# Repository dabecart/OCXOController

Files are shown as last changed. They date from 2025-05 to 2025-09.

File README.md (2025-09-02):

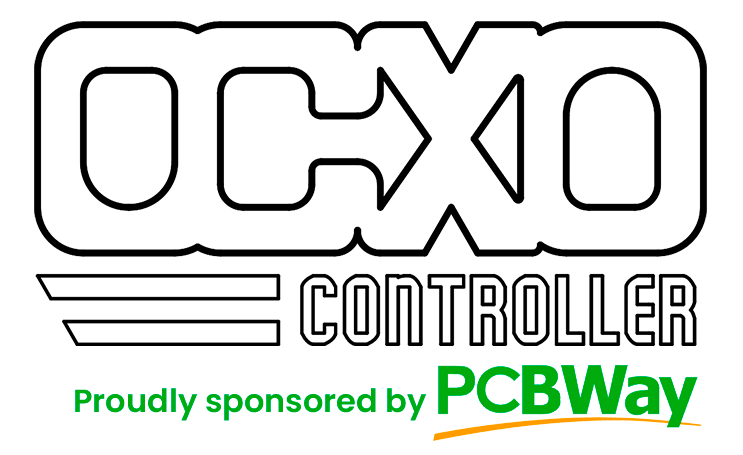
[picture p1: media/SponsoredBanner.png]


# OCXO Controller

By @dabecart, 2025.

✨ This project was sponsored by [**PCBWay**](#a-huge-thank-you-to-pcbway) ✨

Control the frequency of an OCXO (Oven Controlled Crystal Oscillator) to synchronize it with an external
signal of reference. Use it on a radio transmitter or for precision frequency measurement!

# Video

<a href="http://www.youtube.com/watch?feature=player_embedded&v=DMhajk4vEt8
" target="_blank">OCXOControllerVideo</a>

# Gallery

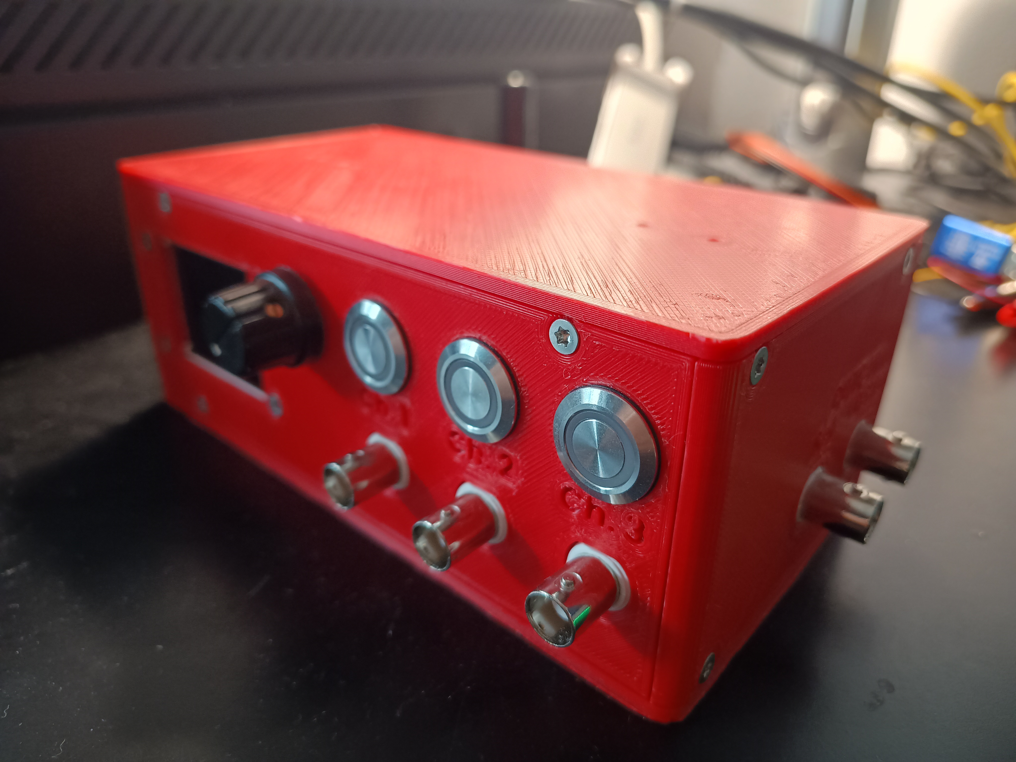
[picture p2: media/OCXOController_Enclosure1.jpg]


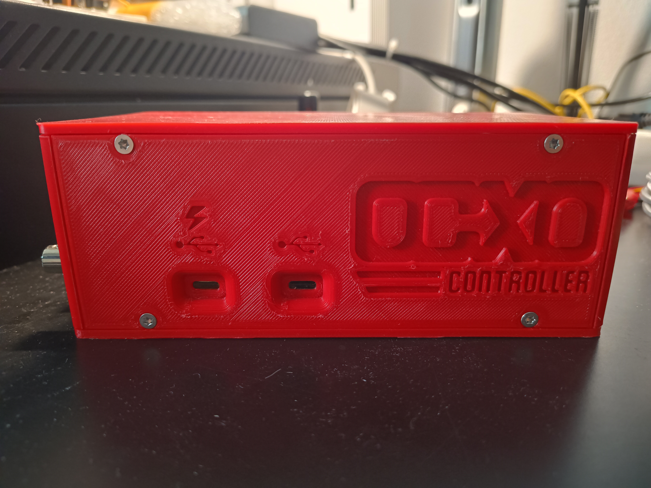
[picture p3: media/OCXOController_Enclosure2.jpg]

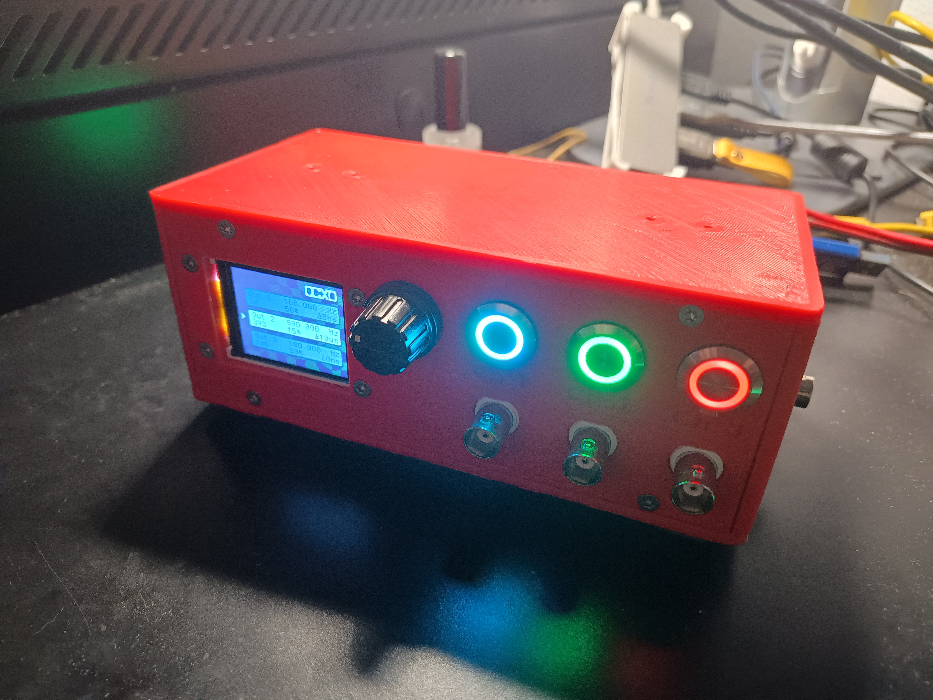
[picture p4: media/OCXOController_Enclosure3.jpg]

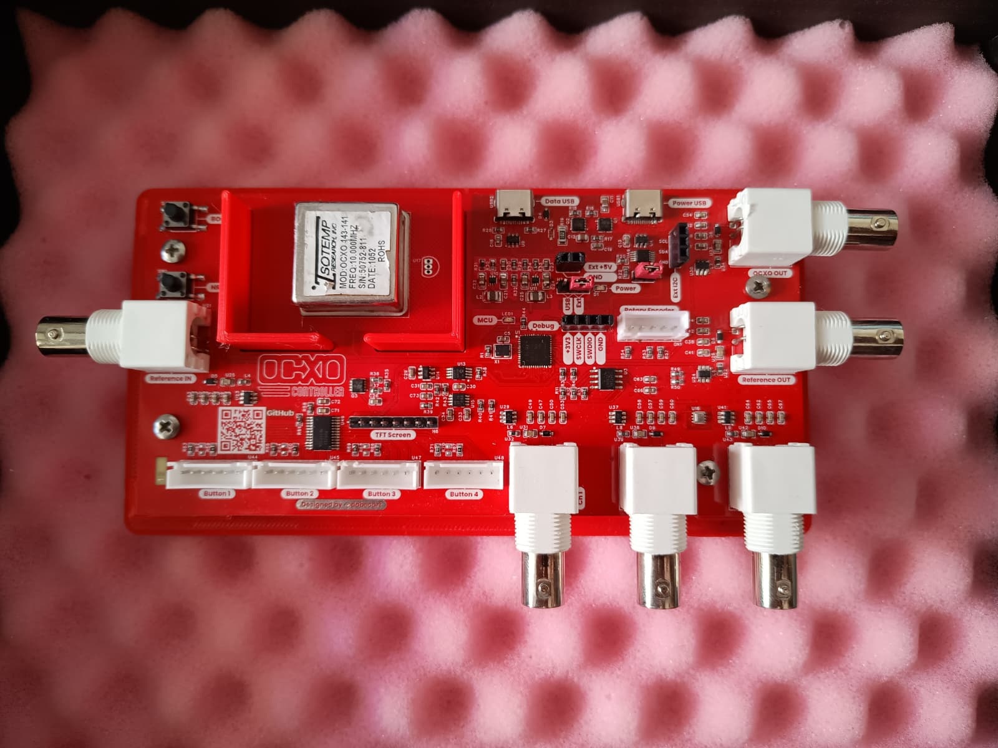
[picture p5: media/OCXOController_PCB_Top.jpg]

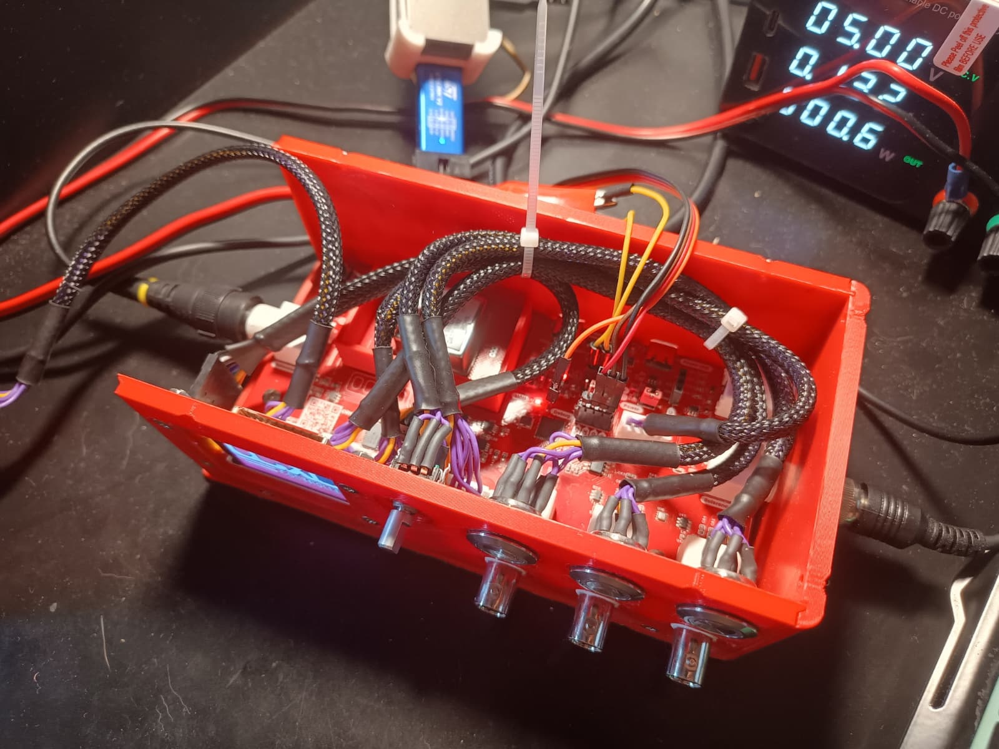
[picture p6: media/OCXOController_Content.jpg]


# A Huge Thank You to PCBWay! 

Whether you're a hobbyist, engineer, or student, I feel confident in saying that they're the go-to destination for high-quality PCB manufacturing and prototyping.

Here are just a few of the reasons why PCBWay stands out:

✅ Top-notch Quality: After thoroughly inspecting all of the PCBs of my project, I was content with the great precision the PCBs were made. I felt they are reliable and durable!

✅ Fast Turnaround: The whole ordering, manufacturing and shipping of the PCBs and the stencil to Spain took around a week and a half, which is most impressing! 

✅ Affordable Pricing: Their competitive rates make professional-grade PCBs accessible to everyone.

✅ Excellent Support: From order placement to final delivery, PCBWay’s team was always there to answer my questions and provide guidance.

Thanks to their expertise and dedication, I was able to turn my ideas for this project into reality without a hitch. If you’re working on your next PCB project, I can’t recommend PCBWay enough!

🎉 Visit [**PCBWay.com**](https://www.pcbway.com/) and experience their amazing service for yourself!

✨ And a final thanks to PCBWay for their patronage! ✨

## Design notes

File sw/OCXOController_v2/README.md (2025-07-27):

# OCXO Controller 

*Created by @dabecart, 2025*

## Notes about the timer's configuration

### TIM1: Receives the OCXO signal and replicates it internally

- Slave mode: Trigger Mode
- Trigger Source: TI2FP2
- Clock source: ETR (OCXO)

Receives the output of the OCXO on its ETR pin (PC4). The OCXO's output is therefore used in TIM1 as its clock source. TIM1 has a counter period of 1, meaning it resets/updates at the same time as the OCXO signal (10 MHz). The trigger output (TRGO) raises a trigger on every update meaning that all timers which use ITR0 (the TRGO of TIM1) and are set as Slave Mode = "External Clock Mode 1", will run at the same frequency as the OCXO.

TIM1 is set as Slave mode: "Trigger Mode" on "TI2FP2" (PA9) which is connected to PPS_REF, the reference signal for the calibration of the OCXO. This is used to start TIM1 at the same time as the PPS_REF. 

Channel 3 is set as "Output Compare" with Pulse = 0 and Mode = "Toggle on match". It will replicate the OCXO signal but at a 3V3 level.

**NOTE.** By setting the counter period to 1, the clock signal is being divided by 2, that is, 5MHz is being put into the ITR0, not 10! The counter period cannot be 0, the TIM doesn't turn on with this value...

### TIM5: Divides the OCXO signal down to the reference PPS frequency

- Slave mode: External Clock Mode 1
- Trigger source: ITR0
- Clock source: (TIM1 -> OCXO)

This timer was used as a hack to not route the OCXO_OUT signal to multiple pins, but also it is in charge of dividing the OCXO frequency down to the frequency of the reference PPS. This is accomplished by setting the "Prescaler" to 999 and the "Counter period" to 4999. This converts a 10 MHz signal to 1 Hz. 

Channel 2 is set as "Output Compare" (PA1). On this pin the divided OCXO signal will be generated.

TIM5 generates a TRGO (Trigger Output) on the Output Compare 2. This is used to start at the same time the timestamping clocks (TIM2 and TIM15).

**NOTE.** As previously said, ITR0 is 5MHz not 10MHz, therefore the Counter Period must be 2499. 

### TIM2: Timestamps the OCXO output divided down to the PPS reference frequency

- Slave mode: Trigger Mode
- Trigger Source: ITR4
- Clock source: Internal

TIM2 is used to get the timestamps of the OCXO output after being divided to the reference PPS' frequency. These timestamps will be compared to the timestamps of the reference PPS to tune the OCXO. 

The shrinked down OCXO signal is being replicated by TIM5 at pin PA1. Channel 1 (PA0) and Channel 3 (PA2) are set as "Input Capture direct mode". They will timestamp the rising and falling edge of the divided OCXO signal.

Note: TIM2 is a 32 bit timer. As timestamps are being made in TIM2 and TIM15, they should have the same range. That is why TIM2 has its "Counter Period" set to 65535, to match that of TIM15.

TIM2 is set as Slave Mode "Trigger Mode" with Trigger Source "ITR4" so that this timer starts working on the first pulse of the divided OCXO signal.

### TIM15: Timestamps the PPS reference

- Slave mode: Trigger Mode
- Trigger Source: ITR4
- Clock source: Internal

TIM15 is used to timestamp with the clock of the microcontroller the rising and falling edges of the PPS_REF signal. Channel 1 (PB15) and 2 (PB14) are set as "Input Capture direct mode".

TIM15 is set as Slave Mode "Trigger Mode" with Trigger Source "ITR4" so that this timer starts working on the the first pulse of the divided OCXO signal.

### TIM3, TIM4, TIM8: Generate the OUT1, OUT2 and OUT3 signals

- Slave mode: External Clock Mode 1
- Trigger Source: ITR0
- Clock source: (TIM1 -> OCXO)

These timers each have a single channel set as "PWM Generation". They are used to generate PWM outputs. The "Counter Period" can be used in combination with the "Prescaler" to set the frequency of the PWM. The "Pulse" of the PWM controls the duty cycle. To set the phase of the signals, the counter of the TIMx can be set initially to a specific value. The only thing about the phase is that during this the ITR0 must be deactivated (TIM1 must not generate a signal).

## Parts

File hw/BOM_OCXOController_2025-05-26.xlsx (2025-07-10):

No. | Quantity | Comment | Designator | Footprint | Value | Manufacturer Part | Manufacturer | Supplier Part | Supplier
1 | 52 | 100n | C1,C2,C3,C4,C8,C9,C10,C12,C13,C14,C18,C26,C28,C29,C30,C31,C33,C34,C35,C36,C37,C38,C39,C40,C41,C42,C43,C44,C45,C46,C47,C48,C49,C50,C51,C52,C53,C54,C55,C56,C57,C58,C59,C60,C61,C62,C63,C64,C65,C67,C68,C71 | C0603 |  | CL10A104KA8NNNC | Samsung Electro-Mechanics
2 | 7 | 10n | C5,C6,C66,C69,C70,C72,C73 | C0603 |  | CL10B103KB8WPNC | Samsung Electro-Mechanics
3 | 6 | 1u | C7,C15,C16,C17,C19,C27 | C0603 |  | CL10B105KO8NNND | Samsung Electro-Mechanics
4 | 1 | 4.7u | C11 | C0805 |  | CL21A475KAQNNNE | SAMSUNG(三星)
5 | 2 | 100pF | C20,C23 | C0603 |  | CL10C101JB8NFNC | SAMSUNG(三星)
6 | 2 | 4.7uF | C21,C24 | C0805 |  | CL21A475KAQNNNE | SAMSUNG(三星)
7 | 2 | 22uF | C22,C25 | C0805 |  | CL21A226MQQNNNF | SAMSUNG(三星) | C307531 | LCSC
8 | 1 | B5B-XH-A(LF)(SN) | CN1 | CONN-TH_B5B-XH-A-LF-SN |  | B5B-XH-A(LF)(SN) | JST | C157991 | LCSC
9 | 2 | 150060RS75000 | D1,LED1 | LED0603-RD_RED |  | 150060RS75000 | Wurth(伍尔特) | C3030991 | LCSC
10 | 1 | ESDA25P35-1U1M | D2 | DFN1610-2_L1.6-W1.0-P1.05-RD |  | ESDA25P35-1U1M | ST(意法半导体) | C1974707 | LCSC
11 | 8 | TSD05DYFR | D3,D4,D5,D6,D7,D8,D9,D10 | SOD-323_L1.7-W1.3-LS2.6-RD-1 |  | TSD05DYFR | TI(德州仪器) | C22396185 | LCSC
12 | 1 | RS1-04-G | H1 | HDR-TH_4P-P2.54-V-F-R1-C4 |  | RS1-04-G | ADAM TECH | C21129526 | LCSC
13 | 1 | PH1-03-UA | H2 | HDR-TH_3P-P2.54-V-M |  | PH1-03-UA | Adam Tech
14 | 1 | RS1-02-G | H3 | HDR-TH_2P-P2.54-V-F |  | RS1-02-G | Adam Tech
15 | 1 | RS1-03-G | H4 | HDR-TH_3P-P2.54-V-M |  | RS1-03-G | Adam Tech
16 | 1 | PH1-02-UA | H5 | HDR-TH_2P-P2.54-V-M-1 |  | PH1-02-UA | Adam Tech
17 | 1 | PH1-08-UA | H6 | HDR-TH_8P-P2.54-V-M |  | PH1-08-UA | Adam Tech
18 | 7 | 742792641 | L1,L4,L5,L6,L7,L8,L9 | L0603 |  | 742792641 | Wurth(伍尔特) | C2649308 | LCSC
19 | 2 | 1uH | L2,L3 | L2520 |  | DFE252012F-1R0M=P2 | muRata(村田) | C435392 | LCSC
20 | 3 | STL6P3LLH6 | Q1,Q2,Q3 | PDFN3333-8L_L3.2-W3.0-P0.65-LS3.3-BL_WILLSEMI_WNM3057XXXX |  | STL6P3LLH6 | ST(意法半导体) | C457492 | LCSC
21 | 33 | 10k | R1,R5,R7,R11,R12,R13,R20,R21,R22,R25,R26,R35,R38,R39,R45,R46,R47,R48,R49,R50,R51,R52,R53,R54,R55,R56,R57,R58,R61,R63,R65,R69,R71 | R0603 |  | RMC16K103FTP | KAMAYA(釜屋電機)
22 | 9 | 0R | R2,R59,R60,R62,R64,R66,R67,R68,R70 | R0603 |  | RMC1/16JPTP | KAMAYA(釜屋電機)
23 | 8 | 4k7 | R3,R4,R15,R40,R41,R42,R43,R44 | R0603 |  | RMC1/16-472JTP | KAMAYA(釜屋電機)
24 | 1 | 330R | R6 | R0603 |  | RMC16K331FTP | KAMAYA(釜屋電機)
25 | 1 | 1k5 | R8 | R0603 |  | RMC1/16-152JTP | KAMAYA(釜屋電機)
26 | 2 | 33R | R9,R10 | R0603 |  | RMC16K330FTP | KAMAYA(釜屋電機)
27 | 1 | 2k2 | R14 | R0603 |  | RMC1/16K2201FTP | KAMAYA(釜屋電機)
28 | 4 | 100k | R16,R29,R32,R34 | R0603 |  | RMC1/16K1003FTP | KAMAYA(釜屋電機)
29 | 1 | 100 | R17 | R0603 |  | RMC16K101FTP | KAMAYA(釜屋電機)
30 | 2 | 22k | R18,R36 | R0603 |  | RMC16K223FTP | KAMAYA(釜屋電機)
31 | 2 | 1k | R19,R24 | R1206 | 1k | RMC1/8-102JTP | KAMAYA(釜屋電機)
32 | 1 | 470 | R23 | R1206 | 470 | RMC1/8-471JTP | KAMAYA(釜屋電機)
33 | 2 | 5k1 | R27,R28 | R0603 |  | RMC16K512FTP | KAMAYA(釜屋電機)
34 | 1 | 360k | R30 | R0603 |  | RMC16K364FTP | KAMAYA(釜屋電機)
35 | 1 | 78.7k | R31 | R0603 |  | RMC1/16K7872FTP | KAMAYA(釜屋電機)
36 | 1 | 200k | R33 | R0603 |  | RMC16K204FTP | KAMAYA(釜屋電機)
37 | 1 | 100R | R37 | R0603 |  | RMC16K101FTP | KAMAYA(釜屋電機) | C323608 | LCSC
38 | 2 | TS04-66-65-BK-160-SMT | SW1,SW2 | SW-SMD_4P-L6.0-W6.0-P4.50-LS10.0-1 |  | TS04-66-65-BK-160-SMT | CUI | C4364797 | LCSC
39 | 1 | STM32G473CBU6 | U1 | UFQFPN-48_L7.0-W7.0-P0.50-BL-EP |  | STM32G473CBU6 | ST(意法半导体)
40 | 3 | ESD321DYAR | U2,U6,U18 | SOD-523-2 |  | ESD321DPYR | TI | C717890 | LCSC
41 | 1 | CAT24C128WI-GT3 | U3 | SOIC-8_L4.9-W3.9-P1.27-LS6.0-BL |  | CAT24C128WI-GT3 | onsemi(安森美) | C81195 | LCSC
42 | 2 | USBLC6-2SC6Y | U4,U9 | SOT-23-6_L2.9-W1.7-P0.95-LS2.8-BL |  | USBLC6-2SC6Y | ST(意法半导体) | C2969755 | LCSC
43 | 1 | STUSB4500QTR | U5 | QFN-24_L4.0-W4.0-P0.50-BL-EP2.8 |  | STUSB4500QTR | ST(意法半导体) | C2678061 | LCSC
44 | 1 | PI3USB102GZLEX | U7 | TQFN-10_L1.6-W1.3-P0.50-TL |  | PI3USB102GZLEX | DIODES(美台) | C155356 | LCSC
45 | 1 | ESDA25W | U8 | SOT-323-3_L2.1-W1.3-P1.32-LS2.1-BR |  | ESDA25W | ST(意法半导体) | C2935152 | LCSC
46 | 2 | TPS62A01DRLR | U10,U11 | SOT-5X3-6_L1.6-W1.2-P0.50-LS1.6-BR |  | TPS62A01DRLR | TI(德州仪器) | C5157937 | LCSC
47 | 1 | AOCJY3A-10.000MHZ | U12 | AOCJY3A10000MHz
48 | 1 | MCP4531T-103E/MS | U13 | MSOP-8_L3.0-W3.0-P0.65-LS4.9-BL |  | MCP4531T-103E/MS | MICROCHIP(美国微芯) | C627270 | LCSC
49 | 1 | MCP4726A3T-E/CH | U14 | SOT-23-6_L2.9-W1.6-P0.95-LS2.8-BR |  | MCP4726A3T-E/CH | MICROCHIP(美国微芯) | C623446 | LCSC
50 | 1 | NCA9306DPH | U15 | TSSOP-8_L3.0-W3.0-P0.65-LS4.0-BL |  | NCA9306DPH | Nexperia(安世) | C5311575 | LCSC
51 | 1 | BME280 | U16 | LGA-8_BME280_BL |  | BME280 | Bosch(博世) | C92489 | LCSC
52 | 1 | DS18B20 | U17 | TO-92-3_L4.9-W3.7-P1.27-L |  | DS18B20 | ADI(亚德诺)/MAXIM(美信) | C9753 | LCSC
53 | 6 | TS5A3359DCUR | U19,U20,U27,U28,U35,U40 | VSSOP-8_L2.1-W2.4-P0.50-LS3.2-BR |  | TS5A3359DCUR | TI(德州仪器) | C478071 | LCSC
54 | 6 | CONBNC002 | U21,U22,U32,U34,U39,U43 | CONBNC002 |  | CONBNC002 | TE Connectivity
55 | 6 | SN74LVC1T45DBVR | U23,U24,U29,U30,U37,U41 | SOT-23-6_L2.9-W1.6-P0.95-LS2.8-BR |  | SN74LVC1T45DBVR | TI(德州仪器) | C7843 | LCSC
56 | 6 | NFM21HC222R1H3D | U25,U26,U31,U33,U38,U42 | FILTER-SMD_3P-L2.0-W1.3-L_NFM21HC222R1H3D |  | NFM21HC222R1H3D | muRata(村田) | C333861 | LCSC
57 | 2 | TCA6416APWR | U36,U46 | TSSOP-24_L7.8-W4.4-P0.65-LS6.4-BL |  | TCA6416APWR | TI(德州仪器) | C130203 | LCSC
58 | 3 | B6B-XH-A(LF)(SN) | U44,U45,U47 | CONN-TH_6P-P2.50_B6B-XH-A-LF-SN |  | B6B-XH-A(LF)(SN) | JST
59 | 1 | B6B-XH-A(LF)(SN) | U48 | CONN-TH_6P-P2.50_B6B-XH-A-LF-SN |  | B6B-XH-A(LF)(SN) | JST |  | LCSC
60 | 2 | 10171746-00021LF | USB1,USB2 | USB-C-SMD_10171746-00021LF |  | 10171746-00021LF | Amphenol | C22466642 | LCSC
61 | 1 | DSC1001CL5-010.0000 | X1 | OSC-SMD_4P-L3.2-W2.5-BL_1C210000BB0F |  | DSC1001CL5-010.0000 | Microchip Technology

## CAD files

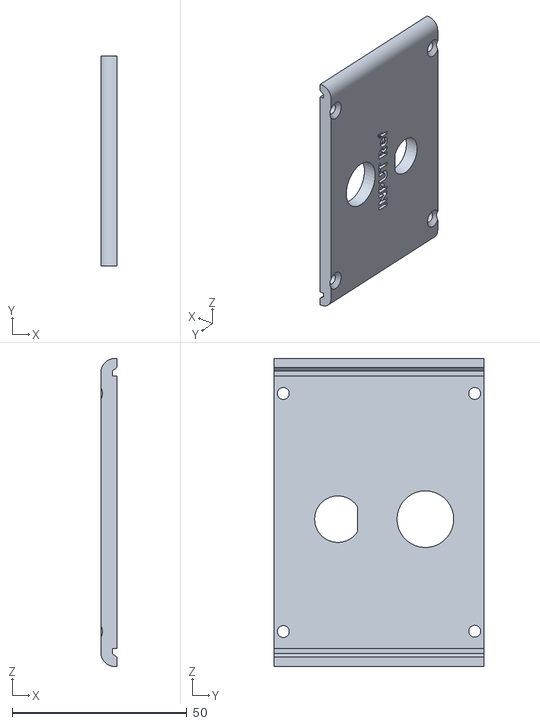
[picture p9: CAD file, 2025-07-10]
mechanics/stl/OCXOController - Left^OCXOController-1.STL
4.70 x 60.0 x 88.0

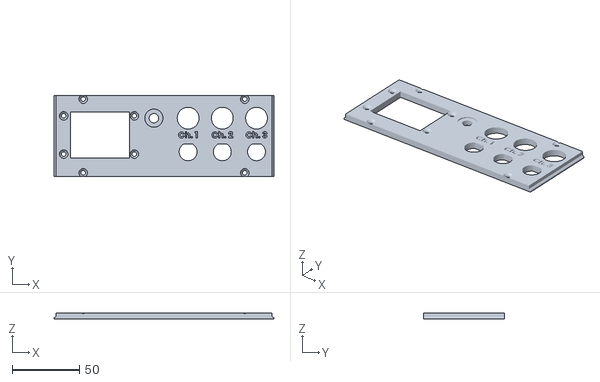
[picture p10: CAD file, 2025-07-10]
mechanics/stl/OCXOController - Front^OCXOController-1.STL
163.4 x 60.0 x 4.70

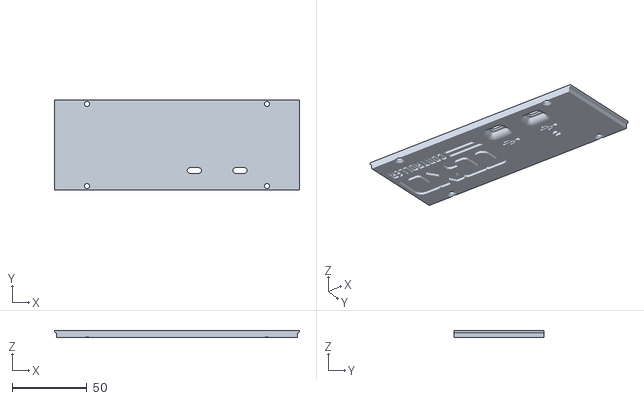
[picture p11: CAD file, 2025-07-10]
mechanics/stl/OCXOController - Back^OCXOController-1.STL
163.4 x 60.0 x 4.80

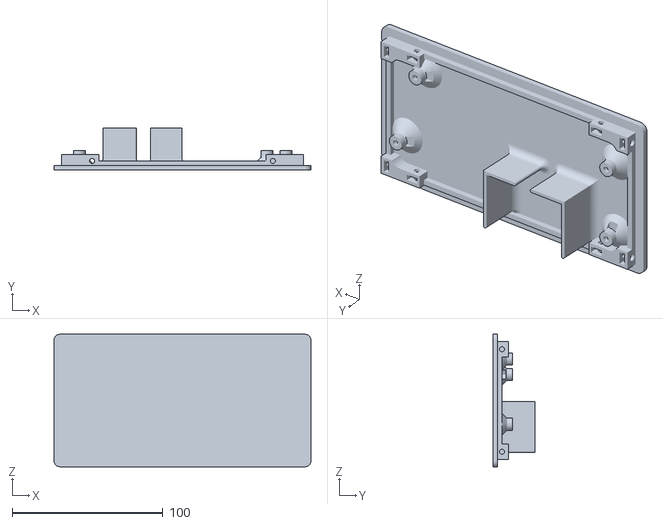
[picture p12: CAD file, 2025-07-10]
mechanics/stl/OCXOController - Base^OCXOController-1.STL
170.6 x 27.6 x 88.0

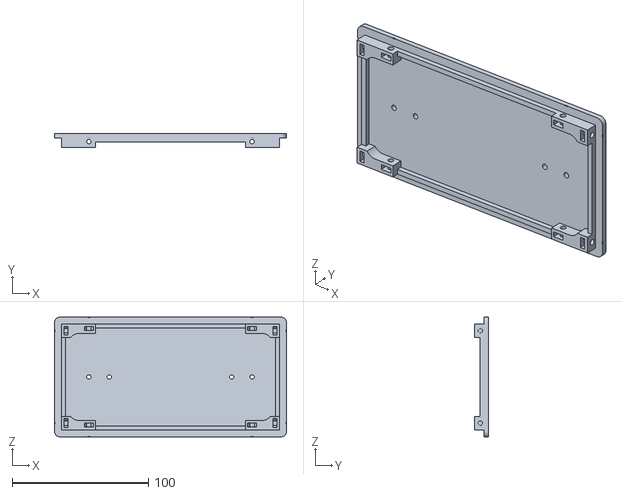
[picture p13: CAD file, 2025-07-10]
mechanics/stl/OCXOController - Part1^OCXOController-1.STL
170.6 x 10.0 x 88.0

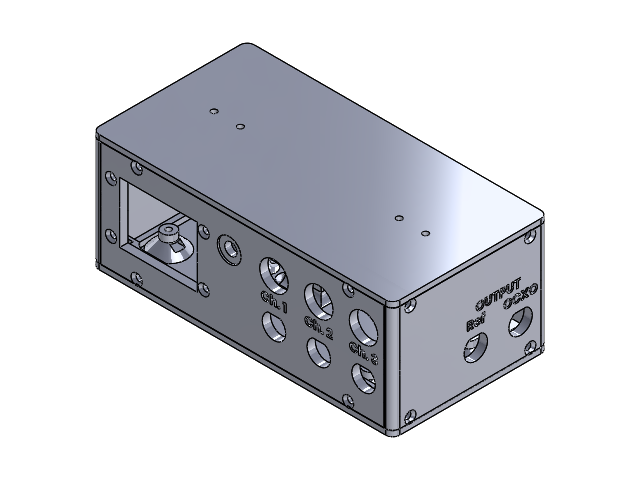
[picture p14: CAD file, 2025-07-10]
mechanics/OCXOController.SLDASM
Base^OCXOController
Left^OCXOController
Right^OCXOController
Front^OCXOController
Back^OCXOController
Part1^OCXOController

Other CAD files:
media/logo/OCXOController_Logo.SLDPRT
mechanics/stl/OCXOController - Right^OCXOController-1.STL
media/logo/OCXOController_Logo.DXF

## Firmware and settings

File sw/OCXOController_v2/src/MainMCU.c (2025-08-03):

#include "MainMCU.h"

MainHandlers hmain;

void initMain(I2C_HandleTypeDef* hi2c1, I2C_HandleTypeDef* hi2c3, 
              SPI_HandleTypeDef* hspi1, DMA_HandleTypeDef* hdma_spi1_tx,
              TIM_HandleTypeDef* htim1, TIM_HandleTypeDef* htim2, TIM_HandleTypeDef* htim3, 
              TIM_HandleTypeDef* htim4, TIM_HandleTypeDef* htim5, TIM_HandleTypeDef* htim6, 
              TIM_HandleTypeDef* htim7, TIM_HandleTypeDef* htim8, TIM_HandleTypeDef* htim15, 
              UART_HandleTypeDef* huart2, 
              DMA_HandleTypeDef* hdma_usart2_rx, DMA_HandleTypeDef* hdma_usart2_tx,
              CORDIC_HandleTypeDef* hcordic) {

    hmain.hi2c1 = hi2c1; 
    hmain.hi2c3 = hi2c3; 
    hmain.hspi1 = hspi1;
    hmain.hdma_spi1_tx = hdma_spi1_tx; 
    hmain.htim1 = htim1; 
    hmain.htim2 = htim2; 
    hmain.htim3 = htim3; 
    hmain.htim4 = htim4; 
    hmain.htim5 = htim5; 
    hmain.htim6 = htim6;
    hmain.htim7 = htim7;
    hmain.htim8 = htim8; 
    hmain.htim15 = htim15; 
    hmain.huart2 = huart2; 
    hmain.hdma_usart2_rx = hdma_usart2_rx; 
    hmain.hdma_usart2_tx = hdma_usart2_tx; 
    hmain.hcordic = hcordic;

    initCORDIC(hcordic);

    uint8_t startupChecks = 1;

    startupChecks &= initGUI(hmain.hspi1, hmain.htim6);
    // Once the GUI has started and its timer is working, set this to initialization. This will make
    // the "tick" of the STM32 be calculated from the IRQ of the GUI instead of the SysTick_Handler.
    hmain.doingInitialization = 1;
    hmain.initialized = 0;

    // Take some time of the initialization to show the logo.
    HAL_Delay(GUI_INITIAL_SCREEN_DELAY_ms);

    // Configure the PD (Power Delivery) chip.
    #if !MCU_POWERED_EXTERNALLY
        logMessage("USB-C...");
        HAL_Delay(GUI_INTERVAL_BETWEEN_INITIALIZATIONS_ms);
        startupChecks &= startSTUSB4500(hi2c3);
        if(startupChecks) logMessage("USB-C OK");
        else{
            logMessage("USB-C ERROR");
            errorTrapMain();
        } 
        HAL_Delay(GUI_INTERVAL_BETWEEN_INITIALIZATIONS_ms);
    #endif

    logMessage("EEPROM...");
    HAL_Delay(GUI_INTERVAL_BETWEEN_INITIALIZATIONS_ms);
    startupChecks &= initEEPROM(&hmain.eeprom, hmain.hi2c3, I2C_ADD_EEPROM);
    if(startupChecks) logMessage("EEPROM OK");
    else{
        logMessage("EEPROM ERROR");
        errorTrapMain();
    } 
    HAL_Delay(GUI_INTERVAL_BETWEEN_INITIALIZATIONS_ms);

    logMessage("DAC Vref...");
    HAL_Delay(GUI_INTERVAL_BETWEEN_INITIALIZATIONS_ms);
    startupChecks &= initDigitalPot(&hmain.pot, hmain.hi2c1, I2C_ADD_POT);
    startupChecks &= setVoltageDigitalPot(&hmain.pot, OCXO_MAX_VCO_VOLTAGE);
    if(startupChecks) logMessage("DAC Vref OK");
    else{
        logMessage("DAC Vref ERROR");
        errorTrapMain();
    } 
    HAL_Delay(GUI_INTERVAL_BETWEEN_INITIALIZATIONS_ms);

    logMessage("DAC...");
    HAL_Delay(GUI_INTERVAL_BETWEEN_INITIALIZATIONS_ms);
    startupChecks &= initMCP4726_DAC(&hmain.dac, hmain.hi2c1, I2C_ADD_DAC);
    if(startupChecks) logMessage("DAC OK");
    else{
        logMessage("DAC ERROR");
        errorTrapMain();
    }
    HAL_Delay(GUI_INTERVAL_BETWEEN_INITIALIZATIONS_ms);

    logMessage("GPIO...");
    HAL_Delay(GUI_INTERVAL_BETWEEN_INITIALIZATIONS_ms);
    startupChecks &= initGPIOController(&hmain.gpio, hmain.hi2c3);
    // The timer + DMA + I2C is not working and causes glitches on the screen.
    // startupChecks &= addTimerAndDMAToGPIOController(&hmain.gpio, hmain.htim7);
    if(startupChecks) logMessage("GPIO OK");
    else{
        logMessage("GPIO ERROR");
        errorTrapMain();
    } 
    HAL_Delay(GUI_INTERVAL_BETWEEN_INITIALIZATIONS_ms);

    logMessage("OCXO...");
    HAL_Delay(GUI_INTERVAL_BETWEEN_INITIALIZATIONS_ms);
    startupChecks &= initOCXOController(hmain.htim15, hmain.htim2, hmain.htim5);
    if(startupChecks) logMessage("OCXO OK");
    else{
        logMessage("OCXO ERROR");
        errorTrapMain();
    } 
    HAL_Delay(GUI_INTERVAL_BETWEEN_INITIALIZATIONS_ms);

    // Set this as connected so that the TIM1 does not get started during the OCXOChannels 
    // initialization.
    hmain.isReferenceSignalConnected = 1;

    logMessage("Channels...");
    HAL_Delay(GUI_INTERVAL_BETWEEN_INITIALIZATIONS_ms);
    startupChecks &= initOCXOChannels(&hmain.chOuts, hmain.htim3, hmain.htim4, hmain.htim8);
    if(startupChecks) logMessage("Channels OK");
    else{
        logMessage("Channels ERROR");
        errorTrapMain();
    } 
    HAL_Delay(GUI_INTERVAL_BETWEEN_INITIALIZATIONS_ms);

    HAL_TIM_OC_Start(hmain.htim1, TIM_CHANNEL_3);
    // Wait for the trigger (the reference PPS) to turn on TIM1.
    logMessage("Awaiting reference...");
    HAL_Delay(GUI_INTERVAL_BETWEEN_INITIALIZATIONS_ms);
    uint32_t t = HAL_GetTick();
    while((HAL_GetTick() - t) < 2500 && ((hmain.htim1->Instance->CR1 & TIM_CR1_CEN) == 0)) {}
    if((hmain.htim1->Instance->CR1 & TIM_CR1_CEN) == 0) {
        // Forcefully activate it.
        hmain.htim1->Instance->CR1 |= TIM_CR1_CEN;
        logMessage("Forced OCXO start");

        hmain.isReferenceSignalConnected = 0;
    }else {
        logMessage("Reference received!");
        
        hmain.isReferenceSignalConnected = 1;
    }
    HAL_Delay(GUI_INTERVAL_BETWEEN_INITIALIZATIONS_ms);

    // Turn on the LED.
    HAL_GPIO_WritePin(TEST_LED_GPIO_Port, TEST_LED_Pin, 1);

    setVoltageLevel(&hmain.gpio, GPIO_OCXO_OUT,     VOLTAGE_LEVEL_5V);
    setVoltageLevel(&hmain.gpio, GPIO_PPS_REF_IN,   VOLTAGE_LEVEL_3V3);
    setVoltageLevel(&hmain.gpio, GPIO_PPS_REF_OUT,   VOLTAGE_LEVEL_5V);

    logMessage("Enjoy!");

    updateGUIInIRQ = 0;
    requestScreenChange(SCREEN_MAIN, NULL, 1);
    
    hmain.initialized = 1;
    hmain.doingInitialization = 0;
}

void loopMain() {
    static uint8_t ocxoOn = 0;

    loopOCXOCOntroller();

    updateGPIOController(&hmain.gpio);

    updateGUI();

    if(hmain.gpio.btn1.isClicked) {
        ocxoOn = !ocxoOn;
        powerOCXO(&hmain.gpio, ocxoOn);
        setButtonColor(&hmain.gpio, BUTTON_1, ocxoOn ? BUTTON_COLOR_GREEN : BUTTON_COLOR_RED);
    }

    if(hmain.gpio.btn2.isClicked) {
        hmain.chOuts.ch1.isOutputON = !hmain.chOuts.ch1.isOutputON;
        applyAllOCXOOutputsFromConfiguration(&hmain.chOuts);
    }

    if(hmain.gpio.btn3.isClicked) {
        hmain.chOuts.ch2.isOutputON = !hmain.chOuts.ch2.isOutputON;
        applyAllOCXOOutputsFromConfiguration(&hmain.chOuts);
    }

    if(hmain.gpio.btn4.isClicked) {
        hmain.chOuts.ch3.isOutputON = !hmain.chOuts.ch3.isOutputON;
        applyAllOCXOOutputsFromConfiguration(&hmain.chOuts);
    }
    
}

void errorTrapMain() {
  for(;;) {
    HAL_GPIO_WritePin(TEST_LED_GPIO_Port, TEST_LED_Pin, 0);
    HAL_Delay(1000);
    HAL_GPIO_WritePin(TEST_LED_GPIO_Port, TEST_LED_Pin, 1);
    HAL_Delay(1000);
  }
}

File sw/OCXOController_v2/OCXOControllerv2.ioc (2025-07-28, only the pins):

Mcu.UserName=STM32G473CBUx
PA0.Signal=S_TIM2_CH1
PA1.GPIO_Label=OCXO_DIVIDED
PA1.Signal=S_TIM5_CH2
PA10.Signal=S_TIM1_CH3
PA11.Signal=USB_DM
PA12.Signal=USB_DP
PA13.Signal=SYS_JTMS-SWDIO
PA14.Signal=SYS_JTCK-SWCLK
PA15.Signal=I2C1_SCL
PA2.Signal=S_TIM2_CH3
PA5.Signal=SPI1_SCK
PA7.Signal=SPI1_MOSI
PA8.Signal=I2C3_SCL
PA9.Signal=S_TIM1_CH2
PB0.GPIO_Label=TFT_A0
PB0.Signal=GPIO_Output
PB1.GPIO_Label=TFT_RESET
PB1.Signal=GPIO_Output
PB11.GPIO_Label=USB_ALERT
PB11.Signal=GPIO_Input
PB12.GPIO_Label=PG_1V8
PB12.Signal=GPIO_Input
PB13.GPIO_Label=PG_3V3
PB13.Signal=GPIO_Input
PB14.Signal=S_TIM15_CH1
PB15.Signal=S_TIM15_CH2
PB2.GPIO_Label=TFT_CS
PB2.Signal=GPIO_Output
PB3.Signal=USART2_TX
PB5.GPIO_Label=CH_OUT3
PB5.Signal=S_TIM3_CH2
PB6.GPIO_Label=CH_OUT2
PB6.Signal=S_TIM8_CH1
PB7.GPIO_Label=CH_OUT1
PB7.Signal=S_TIM4_CH2
PB9.Signal=I2C1_SDA
PC11.Signal=I2C3_SDA
PC13.GPIO_Label=TEST_LED
PC13.Signal=GPIO_Output
PC4.Signal=S_TIM1_ETR
PF0-OSC_IN.Signal=RCC_OSC_IN

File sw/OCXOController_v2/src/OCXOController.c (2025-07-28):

#include "OCXOController.h"
#include "main.h"       // GPIO names.
#include "MainMCU.h"    // DAC handler.

TIM_HandleTypeDef* ppsTim;
TIM_HandleTypeDef* ocxoTim;
TIM_HandleTypeDef* ocxoFreqDivTim;

uint32_t vcoValue = CONTROL_INITIAL_VCO;

LIFO_d risingEdgesFreq;
LIFO_d fallingEdgesFreq;
double risingEdgesFreqArray [CONTROL_POINTS_IN_MEMORY];
double fallingEdgesFreqArray[CONTROL_POINTS_IN_MEMORY];
volatile uint8_t newRisingEdge = 0;
volatile uint8_t newFallingEdge = 0;

// Used on calibration. Stores the timestamps of the rising edges of both signals. This one does not
// get cleared continuously. New values will overwrite the oldest values in the LIFO.
LIFO_u32 risingEdgesPPSRefTimestamps;
LIFO_u32 risingEdgesOCXOTimestamps;
uint32_t risingEdgesPPSRefTimestampsArray[OCXO_CALIBRATION_FREQUENCY_MEASUREMENTS];
uint32_t risingEdgesOCXOTimestampsArray[OCXO_CALIBRATION_FREQUENCY_MEASUREMENTS];

// Used to calculate the relative frequency. It is normally cleared when a pair of timestamps have
// been found that are close enough to generate a relative frequency. If no timestamp is found, the
// values remain on the LIFO until a new pair is found. 
LIFO_u32 risingPPSRef;
LIFO_u32 fallingPPSRef;
uint32_t risingPPSRefArray [CONTROL_CLOSE_POINTS_IN_MEMORY];
uint32_t fallingPPSRefArray[CONTROL_CLOSE_POINTS_IN_MEMORY];

LIFO_u32 risingOCXO;
LIFO_u32 fallingOCXO;
uint32_t risingOCXOArray [CONTROL_CLOSE_POINTS_IN_MEMORY];
uint32_t fallingOCXOArray[CONTROL_CLOSE_POINTS_IN_MEMORY];

// Proportional gain.
double Kp = 0.05;
// Integral gain.
double Ki = 0.002;
// Differential gain.
double Kd = 0.001;
// Low pass filter of the VCO.
double Nf = 0.1;
// Filter of the derivative value.
double Df = 0.1;
// Limits the integral value.
double antiwindupLimit = 0.0001;
// Offset frequency for the generation of the VCO.
double phaseOffset = 0;

// Frequency of the OCXO when VCO = 0V.
double minOCXOFrequency = -OCXO_CONTROL_FREQUENCY_RANGE;
// Frequency of the OCXO when VCO = Vcc.
double maxOCXOFrequency = OCXO_CONTROL_FREQUENCY_RANGE;

uint8_t doingCalibration = 0;

uint32_t currentVCO = CONTROL_INITIAL_VCO;

uint8_t txBuffer[100];
const double TIME_BETWEEN_PPS =  1.0 / PPS_REF_FREQ;
const double timePerIncrement = 1.0 / PPS_TIMER_FREQ;

uint8_t initOCXOController(TIM_HandleTypeDef* ppsTim_, TIM_HandleTypeDef* ocxoTim_, 
                        TIM_HandleTypeDef* ocxoFreqDividerTim_) {
    ppsTim = ppsTim_;
    ocxoTim = ocxoTim_;
    ocxoFreqDivTim = ocxoFreqDividerTim_;

    // Start LIFOs.
    init_LIFO_d(&risingEdgesFreq, risingEdgesFreqArray, CONTROL_POINTS_IN_MEMORY);
    init_LIFO_d(&fallingEdgesFreq, fallingEdgesFreqArray, CONTROL_POINTS_IN_MEMORY);

    init_LIFO_u32(&risingEdgesPPSRefTimestamps, risingEdgesPPSRefTimestampsArray, OCXO_CALIBRATION_FREQUENCY_MEASUREMENTS);
    init_LIFO_u32(&risingEdgesOCXOTimestamps, risingEdgesOCXOTimestampsArray, OCXO_CALIBRATION_FREQUENCY_MEASUREMENTS);

    init_LIFO_u32(&risingPPSRef, risingPPSRefArray, CONTROL_CLOSE_POINTS_IN_MEMORY);
    init_LIFO_u32(&fallingPPSRef, fallingPPSRefArray, CONTROL_CLOSE_POINTS_IN_MEMORY);
    init_LIFO_u32(&risingOCXO, risingOCXOArray, CONTROL_CLOSE_POINTS_IN_MEMORY);
    init_LIFO_u32(&fallingOCXO, fallingOCXOArray, CONTROL_CLOSE_POINTS_IN_MEMORY);

    // Initialization of Frequency Divider. 
    uint8_t status = HAL_TIM_OC_Start(ocxoFreqDividerTim_, TIM_CHANNEL_2) == HAL_OK;

    // Initialization of the timestamping timers.
    status &= HAL_TIM_IC_Start_IT(ppsTim, TIM_CHANNEL_1) == HAL_OK;
//    status &= HAL_TIM_IC_Start_IT(ppsTim, TIM_CHANNEL_2) == HAL_OK;
    __HAL_TIM_DISABLE_IT(ppsTim, TIM_IT_UPDATE);
    
    status &= HAL_TIM_IC_Start_IT(ocxoTim, TIM_CHANNEL_1) == HAL_OK;
//    status &= HAL_TIM_IC_Start_IT(ocxoTim, TIM_CHANNEL_3) == HAL_OK;
    __HAL_TIM_DISABLE_IT(ocxoTim, TIM_IT_UPDATE);

    // Init USB.
    initUSBComms();

    // Carry out the initial calibration.
    // doingCalibration = 1;

    return status;
}

void loopOCXOCOntroller() {
    static uint32_t lastUpdateVCOTime = 0;
    if((HAL_GetTick() - lastUpdateVCOTime) < CONTROL_VCO_UPDATE_TIME_ms) return;

    lastUpdateVCOTime = HAL_GetTick();

    // Find matching timestamps to generate the errors and calculate the new VCO voltage if a new
    // error value is found.
    if(newRisingEdge) {
        hmain.isReferenceSignalConnected = 1;
        hmain.lastReferenceSignalTime = HAL_GetTick();

        newRisingEdge = 0;
        if(doingCalibration) {
            calibrateOCXO(&risingEdgesFreq);
        }else {
            calculateNewVCO_(&risingEdgesFreq);
            // Discrete low pass filter for the VCO.
            currentVCO = currentVCO * Nf + vcoValue * (1.0 - Nf);
        }
    }

    // if(newFallingEdge) {
    //     newFallingEdge = 0;
    //     calculateNewVCO_(&fallingEdgesFreq);
    // }

    // Actuator section.
    setMCP4726DAC(&hmain.dac, currentVCO);

    static uint8_t rxBuffer[512];
    uint32_t rxLen;
    if(readMessageUSB(sizeof(rxBuffer), rxBuffer, &rxLen) && (rxLen > 0)) {
        processUSBMessage_((char*) rxBuffer, rxLen);
    }


    if((HAL_GetTick() - hmain.lastReferenceSignalTime) > OCXO_REFERENCE_TIMEOUT_ms) {
        hmain.isReferenceSignalConnected = 0;
    }
}
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

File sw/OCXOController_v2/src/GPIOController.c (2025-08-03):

#include "GPIOController.h"

volatile GPIOController_IRQStates irqState;

uint8_t initGPIOController(GPIOController* gpioc, I2C_HandleTypeDef* i2cHandler) {
    if(gpioc == NULL || i2cHandler == NULL) return 0;
    
    gpioc->initialized = 1;
    gpioc->hi2c = i2cHandler;
    // If no timer or DMA is added, then the function to be used to get the state of the pin from 
    // the GPIO controller is the "pollin" one, without DMA.
#if GPIO_USE_INDIVIDUAL_READS
    gpioc->getStateFunction = getStateGPIOExpander;
#else 
    gpioc->getStateFunction = getStateGPIOExpanderFromPolling;
#endif

    gpioc->irqState = GPIO_IRQ_NOT_INITIALIZED;

    memset(&gpioc->btn1, 0, sizeof(ButtonData));
    memset(&gpioc->btn2, 0, sizeof(ButtonData));
    memset(&gpioc->btn3, 0, sizeof(ButtonData));
    memset(&gpioc->btn4, 0, sizeof(ButtonData));
    memset(&gpioc->btnRot, 0, sizeof(ButtonData));
    gpioc->btn1.btn = BUTTON_1;
    gpioc->btn2.btn = BUTTON_2;
    gpioc->btn3.btn = BUTTON_3;
    gpioc->btn4.btn = BUTTON_4;
    gpioc->btnRot.btn = BUTTON_ROT;

    uint8_t state = initGPIOExpander(&gpioc->buttonGPIOs, i2cHandler, I2C_ADD_LED_BUTTONS);
    state &= initGPIOExpander(&gpioc->voltagesGPIOs, i2cHandler, I2C_ADD_VOLTAGE_SELECTOR);

    // Set initial output values before setting the GPIOs as outputs.
    state &= setVoltageLevel(gpioc, GPIO_OCXO_OUT,      VOLTAGE_LEVEL_OFF);
    state &= setVoltageLevel(gpioc, GPIO_PPS_REF_IN,    VOLTAGE_LEVEL_OFF);
    state &= setVoltageLevel(gpioc, GPIO_PPS_REF_OUT,   VOLTAGE_LEVEL_OFF);
    state &= setVoltageLevel(gpioc, GPIO_OUT1,          VOLTAGE_LEVEL_OFF);
    state &= setVoltageLevel(gpioc, GPIO_OUT2,          VOLTAGE_LEVEL_OFF);
    state &= setVoltageLevel(gpioc, GPIO_OUT3,          VOLTAGE_LEVEL_OFF);
    state &= powerOCXO(gpioc, 0);

    state &= setButtonColor(gpioc, BUTTON_1, BUTTON_COLOR_OFF);
    state &= setButtonColor(gpioc, BUTTON_2, BUTTON_COLOR_OFF);
    state &= setButtonColor(gpioc, BUTTON_3, BUTTON_COLOR_OFF);
    state &= setButtonColor(gpioc, BUTTON_4, BUTTON_COLOR_OFF);

    // Set directions of the GPIOs.
    state &= setGPIOControllerDirections_(gpioc);

    // Init rotary encoder.
    state &= initRotaryEncoder_(&gpioc->rot, 
                               &gpioc->voltagesGPIOs, GPIO_VOLT_ROT_A, GPIO_VOLT_ROT_B);

    // Boot up animation of the colored buttons.
    state &= initialAnimationGPIOController_(gpioc);

    gpioc->initialized = state;
    return state;
}

uint8_t addTimerAndDMAToGPIOController(GPIOController* hgpio, TIM_HandleTypeDef* htim) {
    if(hgpio == NULL || htim == NULL) return 0;

    hgpio->htim = htim;
    hgpio->getStateFunction = getStateGPIOExpanderFromDMA;
    hgpio->irqState = GPIO_IRQ_IDLE;

    // The timer will trigger an IRQ which will read the I2C devices sequentially through DMA.
    HAL_TIM_Base_Start_IT(htim);

    return 1;
}

void gpioControllerTimerIRQ(GPIOController* hgpio) {
    if(hgpio == NULL || hgpio->irqState != GPIO_IRQ_IDLE) return;

    if(readGPIOExpanderRegisterDMA_(&hgpio->voltagesGPIOs)) {
        hgpio->irqState = GPIO_IRQ_READING_VOLTAGES_GPIO;
    }
}

void gpioControllerDMA(GPIOController* hgpio) {
    if(hgpio == NULL || hgpio->irqState == GPIO_IRQ_IDLE) return;
    
    switch (hgpio->irqState) {
        case GPIO_IRQ_READING_VOLTAGES_GPIO: {
            if(readGPIOExpanderRegisterDMA_(&hgpio->buttonGPIOs)) {
                hgpio->irqState = GPIO_IRQ_READING_BUTTONS_GPIO;
            }
            break;
        }
        
        case GPIO_IRQ_READING_BUTTONS_GPIO: {
            hgpio->irqState = GPIO_IRQ_IDLE;
            break;
        }

        default:    break;
    }
}

uint8_t updateGPIOController(GPIOController* hgpio) {
    if(hgpio == NULL || !hgpio->initialized) return 0;

#if !GPIO_USE_INDIVIDUAL_READS
    // Poll all input registers at once.
    readGPIOExpanderRegisterPolling_(&hgpio->voltagesGPIOs);
    readGPIOExpanderRegisterPolling_(&hgpio->buttonGPIOs);
#endif

    ButtonData* btns[] = {&hgpio->btn1, &hgpio->btn2, &hgpio->btn3, &hgpio->btn4, &hgpio->btnRot};
    
    GPIOEx_State newState;
    ButtonData* currentBtn;
    for(uint8_t i = 0; i < sizeof(btns)/sizeof(ButtonData*); i++) {
        currentBtn = btns[i];

        if(!getButtonState_(hgpio, currentBtn->btn, &newState)) continue;

        if(newState != currentBtn->isPressed) {
            if(newState == GPIOEx_HIGH) {
                currentBtn->isClicked = 1;

                currentBtn->wasClicked = 1;
                currentBtn->lastTimeClicked = HAL_GetTick();
            }else {
            	currentBtn->isClicked = 0;
            }
            currentBtn->isPressed = newState;
        }else {
            // A click only lasts one cycle. On the next call to updateGPIOController it gets 
            // "cleared".
            currentBtn->isClicked = 0;
        }
    }

    updateRotaryEncoder_(&hgpio->rot, hgpio->getStateFunction);

    return 1;
}
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

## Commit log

2025-02-01 Doing some tests with the PID control!
    [ExcelPlotter.xlsx]
2025-02-05 Improved PID, USB connection. Doing some tests now!
    [ExcelPlotter.xlsx]
2025-02-12 Fixed the PID. Results are being excelent! Still I cannot calibrate the OCXO correctly
    [MainMCU.c, Recorder.py]
2025-05-26 Created a new PCB for the OCXO Controller with new MCU. New prototype firmware for this board.
    [OCXOController_Logo.DXF, OCXOController_Logo.SLDPRT]
2025-07-10 Started working on the software for the new PCB
    [AOCJY3A-10.000MHZ-E.stp, BOM_OCXOController_2025-05-26.xlsx, OCXOController - Back^OCXOController-1.STL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]
2025-07-14 Added EEPROM, DAC and Digital Pot drivers. Tested and working!
2025-07-17 Added DMA to ST7735
2025-07-18 Fixed CORDIC bug for normalizing angles. Added new compressed image plotting. Vey efficient!
    [GUI.c]
2025-07-20 Implementing the rotary encoder
2025-07-21 New mirrored mode checkerboard background and dithered printing for emulating transparency
2025-07-27 Working on synching the OCXO with an external PPS signal. Signal generation on the OCXO outputs is not consistent due to a MCU hardware issue which I don't really know how to address...
    [GPIOController.c, MainMCU.c, OCXOChannels.c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]
2025-07-28 Changed divided OCXO generation to PWM. Seems like the timestamping channels are getting triggered at the same time, as the OCXO disciplines well. But there's no consistency on when the output channe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
2025-08-03 Fixed external reference signal detection
    [GPIOController.c, MainMCU.c]
2025-09-03 Reorganized the repo
    [AOCJY3A-10.000MHZ-E.stp, BOM_OCXOController_2025-05-26.xlsx, OCXOController - Back^OCXOController-1.STL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]
